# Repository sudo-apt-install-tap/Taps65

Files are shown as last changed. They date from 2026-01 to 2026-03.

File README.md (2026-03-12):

# Taps65 ⌨️

<div align="center">  ⚠️ <b> This project is deprecated. </b>  
Please check out <b> Tap65 V2 </b> for the current handwired version. </div> <br>

A custom mechanical keyboard project designed to replace my current daily driver.  
Not a showpiece. Not a concept. Something I can actually use every day.

This project documents the full process of designing and building a keyboard from scratch, following **ai03’s keyboard design guide** as a reference.

---

## 📌 About the Project

Taps65 is a personal keyboard project focused on:
- Practical daily usability
- Clean and understandable design
- Learning proper keyboard PCB design workflows

I’m aiming for something reliable, simple, and functional—no unnecessary fluff.

If you’re following along and something doesn’t make sense, ai03’s guide is highly recommended. It explains the fundamentals far better than I can.

---

## 📷 Images

<br> - MCU Schematic  <br>

<br> - USB-C Schematic <br>
pcb front
<br> - PCB Front <br>
pcb back
<br> - PCB Back <br>
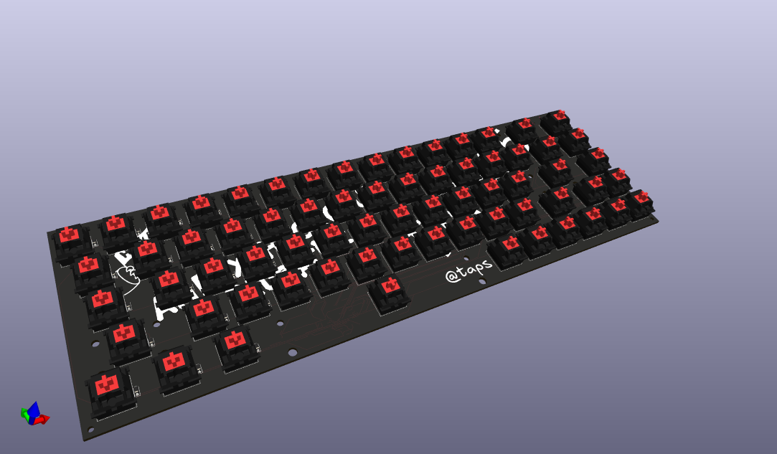
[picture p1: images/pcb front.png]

<br> - PCB Assembled <br>

---

## 🚧 Planned Work

- Add USB protection components ✔
- Key matrix design ✔
- PCB layout ✔
- Plate and case design 
- Firmware (QMK)
- Prototyping and testing

---

## 🤝 Get in Touch

If you want help building your own keyboard or have questions about this project:

### Slack: **@taps**
### Email: **work.tapishnud@gmail.com**

---

## ⚠️ Disclaimer

This is a learning project. Things may break, change, or be redesigned multiple times.  
That’s part of the process.

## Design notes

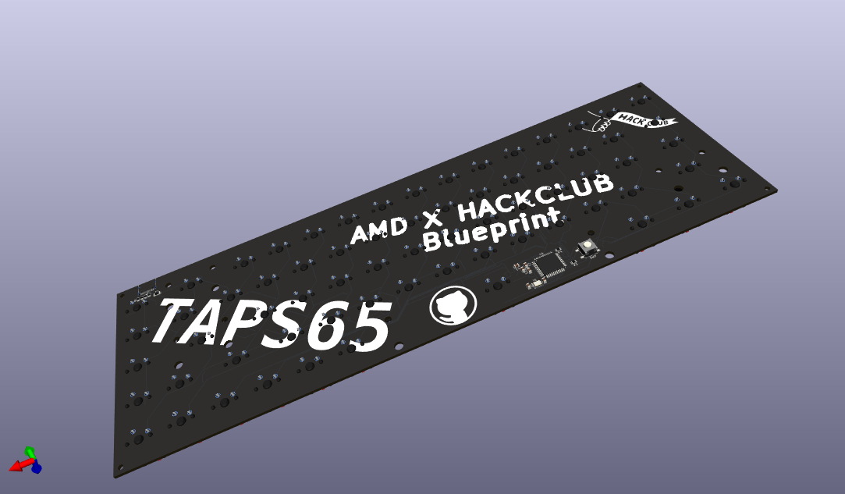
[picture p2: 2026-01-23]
images/pcb back.png

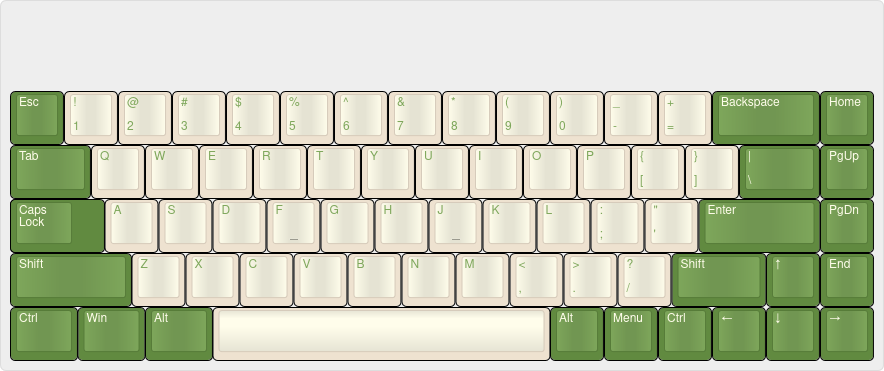
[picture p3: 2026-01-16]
images/keyboard-layout.png

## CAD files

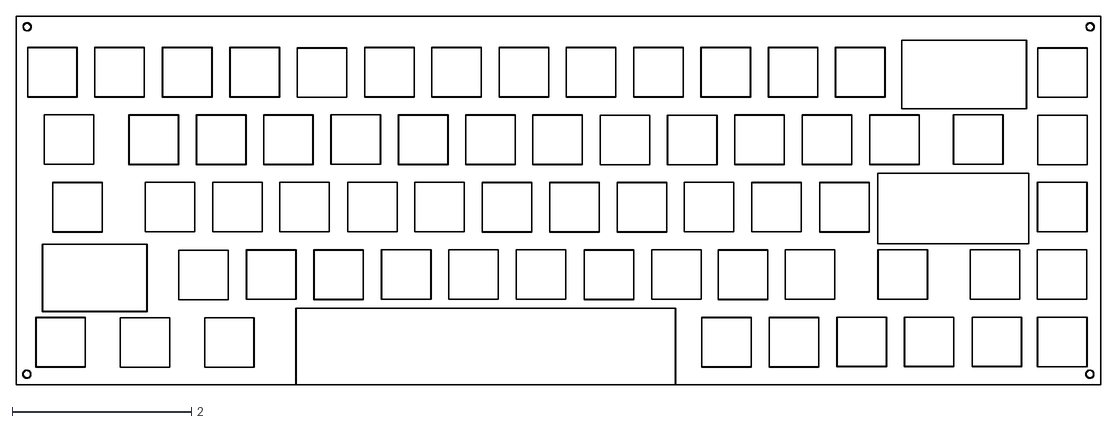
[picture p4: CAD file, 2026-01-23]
CAD/PLATE/pcb-Edge_Cuts.dxf
12.1 x 4.11

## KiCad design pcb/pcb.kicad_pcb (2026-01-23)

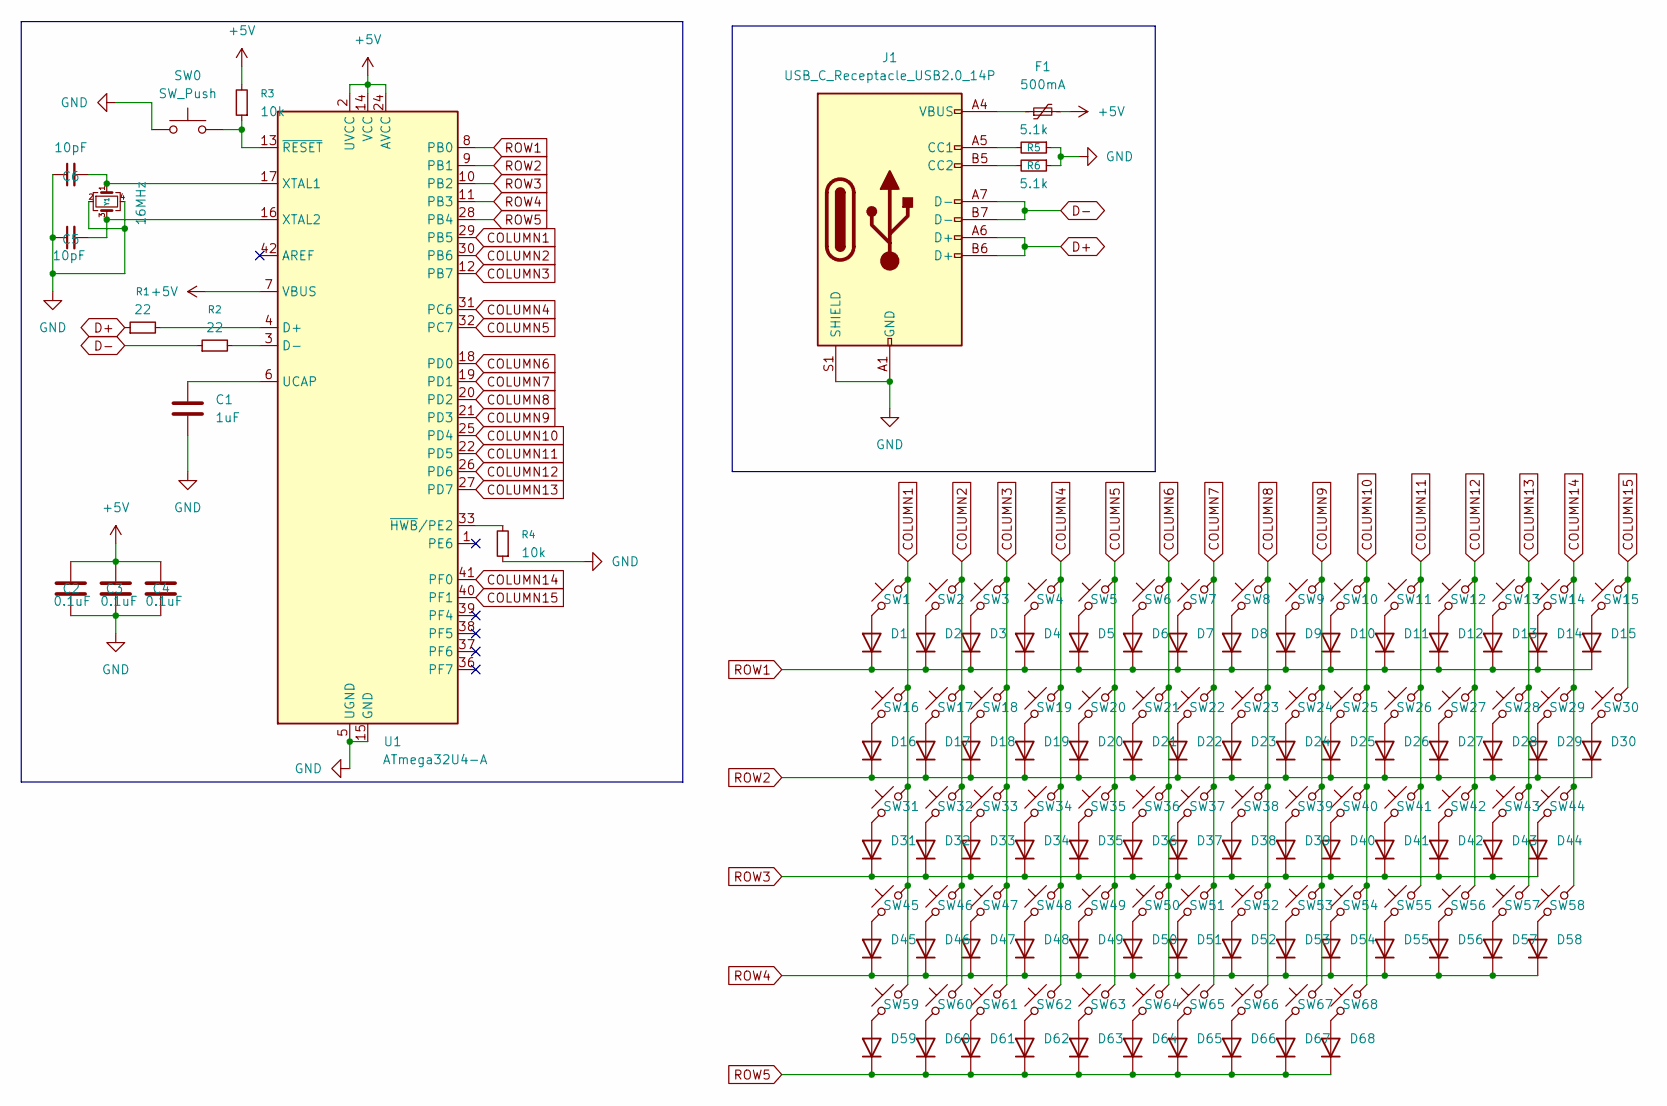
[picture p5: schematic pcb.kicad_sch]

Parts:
C1: 1uF; C_0805_2012Metric
C2, C3, C4: 0.1uF; C_0805_2012Metric
C5, C6: 10pF; C_0805_2012Metric
D1, D2, D3, D4, D5, D6, D7, D8, D9, D10, D11, D12, D13, D14, D15, D16, D17, D18, D19, D20, D21, D22, D23, D24, D25, D26, D27, D28, D29, D30, D31, D32, D33, D34, D35, D36, D37, D38, D39, D40, D41, D42, D43, D44, D45, D46, D47, D48, D49, D50, D51, D52, D53, D54, D55, D56, D57, D58, D59, D60, D61, D62, D63, D64, D65, D66, D67, D68: 1N4148WT; D_SOD-123
F1: 500mA; Fuse_1206_3216Metric
J1: USB_C_Receptacle_USB2.0_14P; USB_C_Receptacle_Amphenol_12401548E4-2A
R1, R2: 22; R_0805_2012Metric
R3, R4: 10k; R_0805_2012Metric
R5, R6: 5.1k; R_0805_2012Metric
SW0: SW_Push; SW_SPST_B3S-1000
SW1, SW2, SW3, SW4, SW5, SW6, SW7, SW8, SW9, SW10, SW11, SW12, SW13, SW14, SW17, SW18, SW19, SW20, SW21, SW22, SW23, SW24, SW25, SW26, SW27, SW28, SW29, SW32, SW33, SW34, SW35, SW36, SW37, SW38, SW39, SW40, SW41, SW42, SW43, SW46, SW47, SW48, SW49, SW50, SW51, SW52, SW53, SW54, SW55, SW57, SW58: SW_Push_45deg; SW_Cherry_MX_1.00u_PCB
SW15: SW_Push_45deg; SW_Cherry_MX_2.00u_PCB
SW16, SW30: SW_Push_45deg; SW_Cherry_MX_1.50u_PCB
SW31, SW56: SW_Push_45deg; SW_Cherry_MX_1.75u_PCB
SW44, SW45: SW_Push_45deg; SW_Cherry_MX_2.25u_PCB
SW59, SW60, SW61, SW63, SW64, SW65, SW66, SW67, SW68: SW_Push_45deg; SW_Cherry_MX_1.00u_Plate
SW62: SW_Push_45deg; SW_Cherry_MX_6.25u_PCB
U1: ATmega32U4-A; TQFP-44_10x10mm_P0.8mm
Y1: 16MHz; Crystal_SMD_3225-4Pin_3.2x2.5mm

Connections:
+5V: C2.1, C3.1, C4.1, F1.2, R3.2, U1.2 (UVCC), U1.7 (VBUS), U1.14 (VCC), U1.24 (AVCC), U1.34 (VCC), U1.44 (AVCC)
COLUMN1: SW1.2, SW16.2, SW31.2, SW45.2, SW59.2, U1.29 (PB5)
COLUMN2: SW2.2, SW17.2, SW32.2, SW46.2, SW60.2, U1.30 (PB6)
COLUMN3: SW3.2, SW18.2, SW33.2, SW47.2, SW61.2, U1.12 (PB7)
COLUMN4: SW4.2, SW19.2, SW34.2, SW48.2, SW62.2, U1.31 (PC6)
COLUMN5: SW5.2, SW20.2, SW35.2, SW49.2, SW63.2, U1.32 (PC7)
COLUMN6: SW6.2, SW21.2, SW36.2, SW50.2, SW64.2, U1.18 (PD0)
COLUMN7: SW7.2, SW22.2, SW37.2, SW51.2, SW65.2, U1.19 (PD1)
COLUMN8: SW8.2, SW23.2, SW38.2, SW52.2, SW66.2, U1.20 (PD2)
COLUMN9: SW9.2, SW24.2, SW39.2, SW53.2, SW67.2, U1.21 (PD3)
COLUMN10: SW10.2, SW25.2, SW40.2, SW54.2, SW68.2, U1.25 (PD4)
COLUMN11: SW11.2, SW26.2, SW41.2, SW55.2, U1.22 (PD5)
COLUMN12: SW12.2, SW27.2, SW42.2, SW56.2, U1.26 (PD6)
COLUMN13: SW13.2, SW28.2, SW43.2, SW57.2, U1.27 (PD7)
COLUMN14: SW14.2, SW29.2, SW44.2, SW58.2, U1.41 (PF0)
COLUMN15: SW15.2, SW30.2, U1.40 (PF1)
D+: J1.A6 (D+), J1.B6 (D+), R1.1
D-: J1.A7 (D-), J1.B7 (D-), R2.1
GND: C1.2, C2.2, C3.2, C4.2, C5.1, C6.1, J1.A1 (GND), J1.A12 (GND), J1.B1 (GND), J1.B12 (GND), J1.S1 (SHIELD), R4.1, R5.1, R6.1, SW0.1, U1.5 (UGND), U1.15 (GND), U1.23 (GND), U1.35 (GND), U1.43 (GND), Y1.2, Y1.4
unnamed: D1.2 (A), SW1.1
unnamed: D2.2 (A), SW2.1
unnamed: D3.2 (A), SW3.1
unnamed: D4.2 (A), SW4.1
unnamed: D5.2 (A), SW5.1
unnamed: D6.2 (A), SW6.1
unnamed: D7.2 (A), SW7.1
unnamed: D8.2 (A), SW8.1
unnamed: D9.2 (A), SW9.1
unnamed: D10.2 (A), SW10.1
unnamed: D11.2 (A), SW11.1
unnamed: D12.2 (A), SW12.1
unnamed: D13.2 (A), SW13.1
unnamed: D14.2 (A), SW14.1
unnamed: D15.2 (A), SW15.1
unnamed: D16.2 (A), SW16.1
unnamed: D17.2 (A), SW17.1
unnamed: D18.2 (A), SW18.1
unnamed: D19.2 (A), SW19.1
unnamed: D20.2 (A), SW20.1
unnamed: D21.2 (A), SW21.1
unnamed: D22.2 (A), SW22.1
unnamed: D23.2 (A), SW23.1
unnamed: D24.2 (A), SW24.1
unnamed: D25.2 (A), SW25.1
unnamed: D26.2 (A), SW26.1
unnamed: D27.2 (A), SW27.1
unnamed: D28.2 (A), SW28.1
unnamed: D29.2 (A), SW29.1
unnamed: D30.2 (A), SW30.1
unnamed: D31.2 (A), SW31.1
unnamed: D32.2 (A), SW32.1
unnamed: D33.2 (A), SW33.1
unnamed: D34.2 (A), SW34.1
unnamed: D35.2 (A), SW35.1
unnamed: D36.2 (A), SW36.1
unnamed: D37.2 (A), SW37.1
unnamed: D38.2 (A), SW38.1
unnamed: D39.2 (A), SW39.1
unnamed: D40.2 (A), SW40.1
unnamed: D41.2 (A), SW41.1
unnamed: D42.2 (A), SW42.1
unnamed: D43.2 (A), SW43.1
unnamed: D44.2 (A), SW44.1
unnamed: D45.2 (A), SW45.1
unnamed: D46.2 (A), SW46.1
unnamed: D47.2 (A), SW47.1
unnamed: D48.2 (A), SW48.1
unnamed: D49.2 (A), SW49.1
unnamed: D50.2 (A), SW50.1
unnamed: D51.2 (A), SW51.1
unnamed: D52.2 (A), SW52.1
unnamed: D53.2 (A), SW53.1
unnamed: D54.2 (A), SW54.1
unnamed: D55.2 (A), SW55.1
unnamed: D56.2 (A), SW56.1
unnamed: D57.2 (A), SW57.1
unnamed: D58.2 (A), SW58.1
unnamed: D59.2 (A), SW59.1
unnamed: D60.2 (A), SW60.1
unnamed: D61.2 (A), SW61.1
unnamed: D62.2 (A), SW62.1
unnamed: D63.2 (A), SW63.1
unnamed: D64.2 (A), SW64.1
unnamed: D65.2 (A), SW65.1
unnamed: D66.2 (A), SW66.1
unnamed: D67.2 (A), SW67.1
unnamed: D68.2 (A), SW68.1
unnamed: F1.1, J1.A4 (VBUS), J1.A9 (VBUS), J1.B4 (VBUS), J1.B9 (VBUS)
unnamed: J1.A5 (CC1), R5.2
unnamed: J1.B5 (CC2), R6.2
unnamed: R1.2, U1.4 (D+)
unnamed: R2.2, U1.3 (D-)
unnamed: C1.1, U1.6 (UCAP)
unnamed: C6.2, U1.17 (XTAL1), Y1.1
unnamed: C5.2, U1.16 (XTAL2), Y1.3
unnamed: R4.2, U1.33 (~HWB/PE2)
unnamed: R3.1, SW0.2, U1.13 (~RESET)
ROW1: D1.1 (K), D2.1 (K), D3.1 (K), D4.1 (K), D5.1 (K), D6.1 (K), D7.1 (K), D8.1 (K), D9.1 (K), D10.1 (K), D11.1 (K), D12.1 (K), D13.1 (K), D14.1 (K), D15.1 (K), U1.8 (PB0)
ROW2: D16.1 (K), D17.1 (K), D18.1 (K), D19.1 (K), D20.1 (K), D21.1 (K), D22.1 (K), D23.1 (K), D24.1 (K), D25.1 (K), D26.1 (K), D27.1 (K), D28.1 (K), D29.1 (K), D30.1 (K), U1.9 (PB1)
ROW3: D31.1 (K), D32.1 (K), D33.1 (K), D34.1 (K), D35.1 (K), D36.1 (K), D37.1 (K), D38.1 (K), D39.1 (K), D40.1 (K), D41.1 (K), D42.1 (K), D43.1 (K), D44.1 (K), U1.10 (PB2)
ROW4: D45.1 (K), D46.1 (K), D47.1 (K), D48.1 (K), D49.1 (K), D50.1 (K), D51.1 (K), D52.1 (K), D53.1 (K), D54.1 (K), D55.1 (K), D56.1 (K), D57.1 (K), D58.1 (K), U1.11 (PB3)
ROW5: D59.1 (K), D60.1 (K), D61.1 (K), D62.1 (K), D63.1 (K), D64.1 (K), D65.1 (K), D66.1 (K), D67.1 (K), D68.1 (K), U1.28 (PB4)

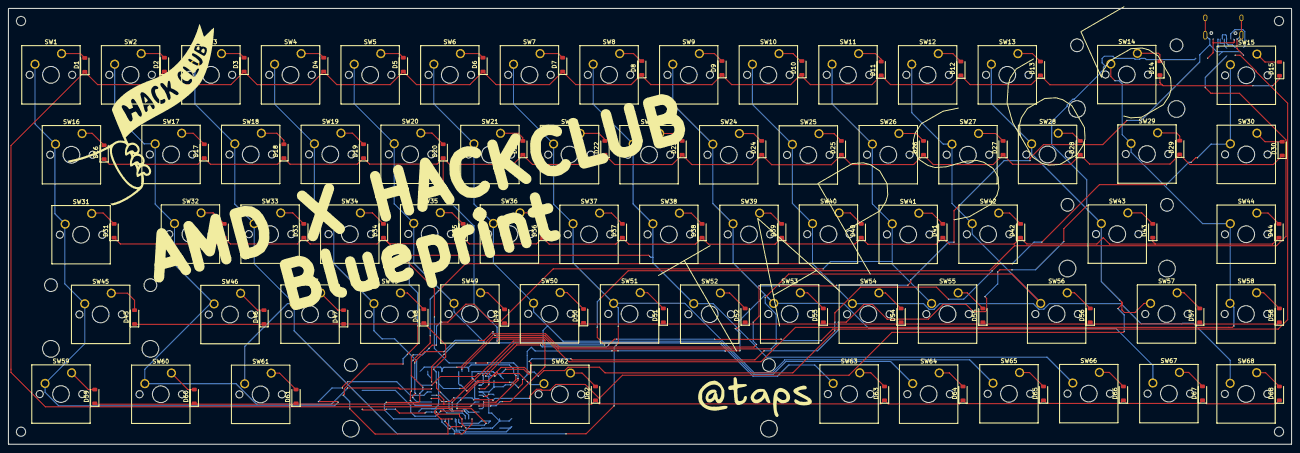
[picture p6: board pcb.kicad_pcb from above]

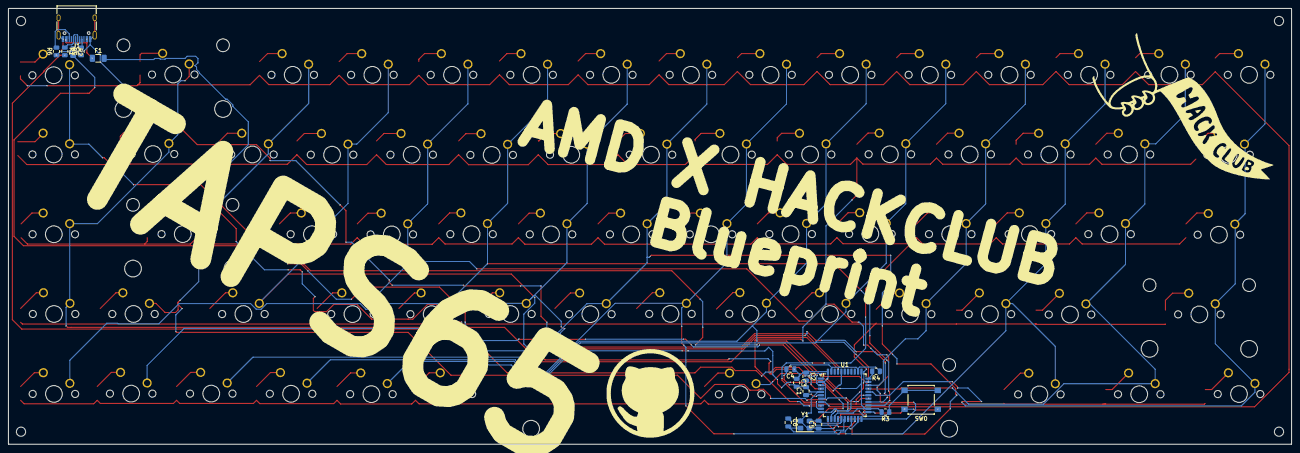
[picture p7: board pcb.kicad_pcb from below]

Board: 2 copper layers, 306.9 x 104.2 mm, 155 parts (18 on the bottom side), 102 nets.

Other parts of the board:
*: LOGO
*#2: LOGO

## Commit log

2026-01-14 Added PCB Layout
    [pcb.kicad_pcb, pcb.kicad_sch]
2026-01-16 Added Images - Finished Routing - Added silkscreen
    [pcb.kicad_pcb, pcb.kicad_sch]
2026-01-16 Update README with additional PCB images
    Added additional images of PCB front and back to the README.
2026-01-16 Rerouted - New Layout
    [pcb.kicad_pcb]
2026-01-23 Updated Images
    [pcb-Edge_Cuts.dxf, pcb.kicad_pcb]
